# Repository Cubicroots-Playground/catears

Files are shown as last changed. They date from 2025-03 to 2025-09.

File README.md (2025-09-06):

# catears

This repository contains everything you need to build your own brightly lit cat ear hairband with widely adopted electronics.

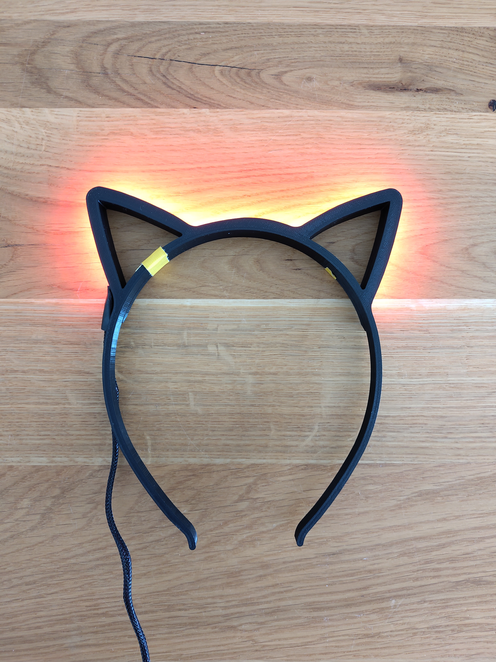
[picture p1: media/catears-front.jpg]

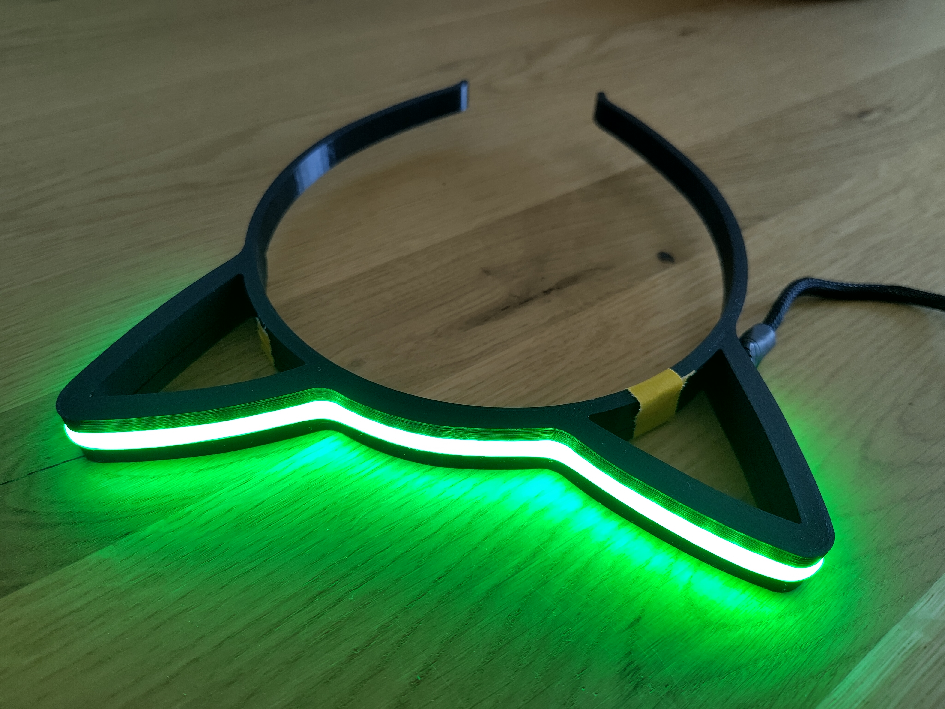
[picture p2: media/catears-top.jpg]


## Why?

This project got inspired by the satirical "Safety cat ears required" signs you might see in some hackspaces or at chaos events. Half joking I once said I will actually build "real" safety cat ears. This repository is the result of that.

## Build your own ones - Step by step!

### Item List

You will need the following items:

- Part 1 & 2 from the `models` folder printed with any 3D printer
- An enclosure for the microcontroller, I am using [this model](https://www.thingiverse.com/thing:4802020)
- 1x ESP8266 (I am using a "Wemos D1 Mini")
- 1x a few centimeters of a WS2811 LED strip 
- A bunch of cables to solder everything together (preferably flexible cable)
  - Either use a 3 core sealed cable or wrap 3 wires with a cable sleeve
- A button with 2 wires attached
- A Micro-USB to USB cable (can be pretty short)
- A USB power source (e.g. a power bank)
- Optional: A connector to solder between microcontroller and cat ears (e.g. JST SM 3 Pin)
- Some glue or tape to connect the 3D printed parts

Further, access to the following tools is needed:

- A soldering station/kit
- A computer with docker for the initial setup

#### Alternative Hardware

You totally can use other hardware components - some notes on swapping parts:

**Microcontroller**

Every microcontroller supported by ESPHome should work. At least 1 GPIO pin should be accessible. Using a different microcontroller requires adopting the ESPHome config.

**LED strip**

Looks best with a silicon diffusor on top - strips are available with a pre-applied one. Search for "COB" or "FCOB" LED strips with the WS2811 chip set.

You can use any other LED strip supported by ESPHome and the neopixel integration. However, using a different chip set requires to adopt the ESPHome config accordingly.

The 3D models are designed to accomodate a 12mm wide LED strip with a 2.65mm wide silicon diffusor on top.

#### Fitting the 3D printed Hairband

You can scale the hairband according to your needs. I seem to have a pretty big head, so the supplied model already is pretty large. It is roughly 20% larger than the "usual" cat ear hairbands in my hackspace. 

To scale the models import them into your favorite slicer and scale the x/y axis for the same amount (do not touch the z axis/height).

### Putting it together

See [the manual](./manual.md).

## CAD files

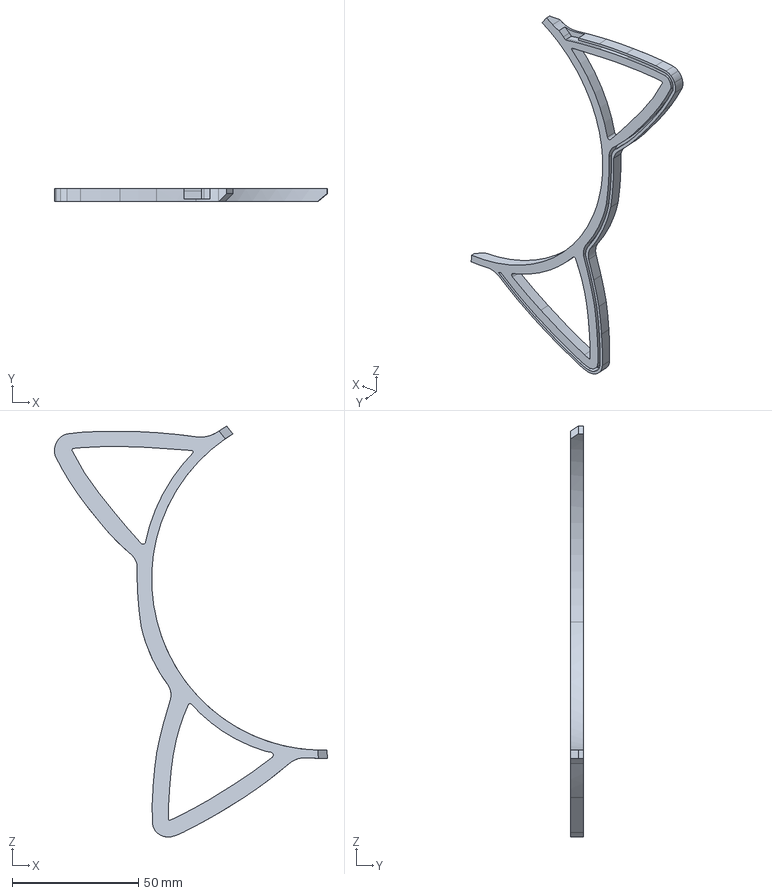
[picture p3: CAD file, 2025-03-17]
models/catears_part_2.FCStd
108.2 x 5.00 x 162.8 mm

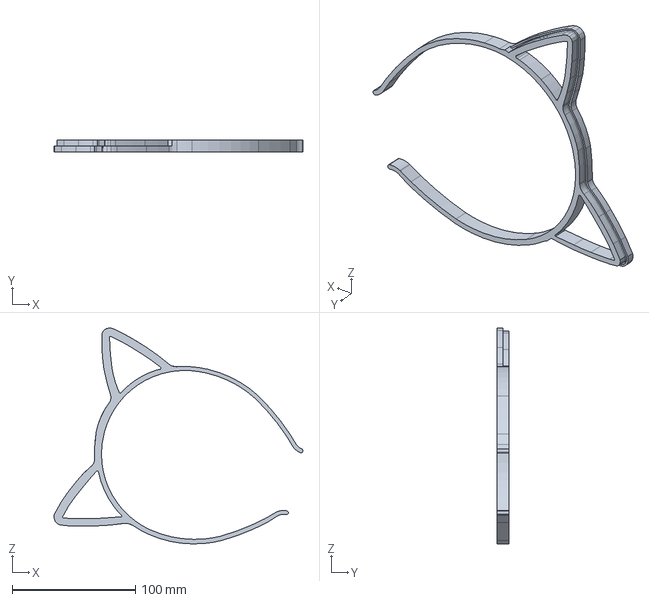
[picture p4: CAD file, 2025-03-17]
models/catears_part_1.FCStd
201.9 x 10.0 x 175.0 mm

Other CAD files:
models/catears_part_1.stl
models/catears_part_2.stl

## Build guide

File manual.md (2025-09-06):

# Manual: Putting it together

1. Print the hairband. Part 1 & 2 are needed.
   
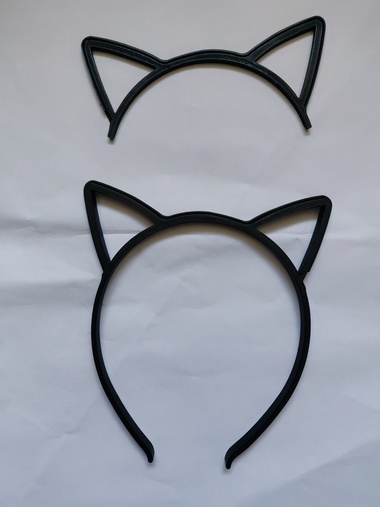
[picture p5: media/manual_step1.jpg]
   
2. Print an enclosure for the microcontroller. I am using [this model](https://www.thingiverse.com/thing:4802020)

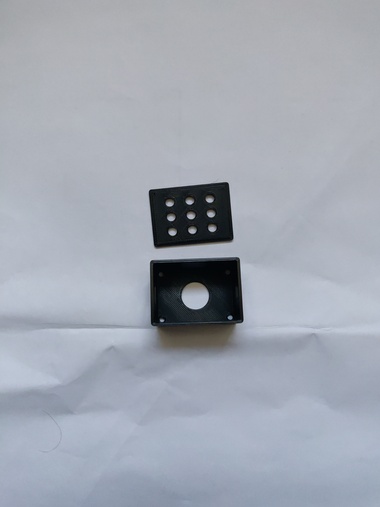
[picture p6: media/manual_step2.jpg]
   
3. Solder wires to your LED strip and connect them with the microcontroller.
   1. You can use a connector between them to easily plug and unplug them. I am using a "JST SM" connector.
   2. To make things look way more nice I suggest covering the cables with some cable sleeves.
   3. The LED strip runs on 5V.
   4. Connect the data wire of the LED strip to your microcontrollers `GPIO3` pin.
   
4. Install the Button
   1. Connect the Button to the 3V and GPIO16 pin.
   
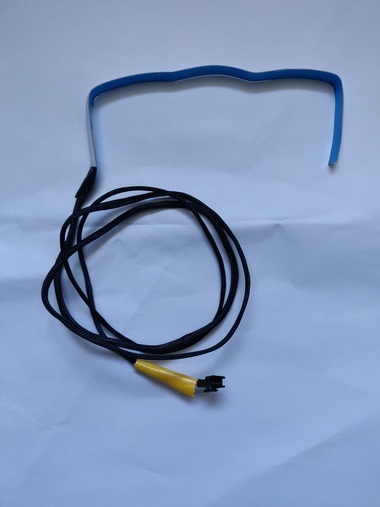
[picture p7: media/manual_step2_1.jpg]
   
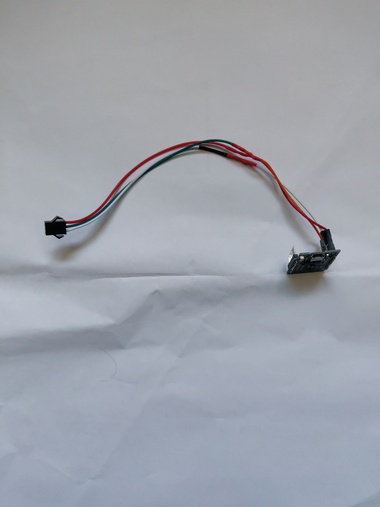
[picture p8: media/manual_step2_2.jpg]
   
5. Assemble the models.
   1. Put the LED strip into the thin groove along the top of the hairband of the bigger of the 2 models.
   2. Cut the LED strip to size.
   
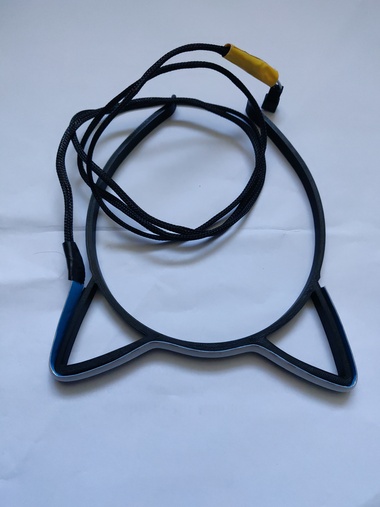
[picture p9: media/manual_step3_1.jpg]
   

   3. Put the second, smaller part on top and make sure the LED strip is fitting into its groove as well.
   4. Glue the parts together or use 2 thin strips of tape to hold them together.
   
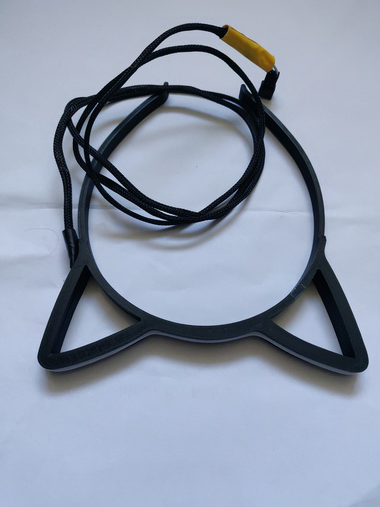
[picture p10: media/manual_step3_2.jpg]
   
6. Flash the microcontroller.
   1. Copy `esphome/secrets.example.yaml` to `esphome/secrets.yaml` and set your secrets.
   2. Connect the microcontroller to your computer via a USB cable.
   3. In a terminal run `(cd esphome && docker compose up)`
   4. Navigate your browser to `http://127.0.0.1:6052`.
   5. LogIn with user `admin` and password `admin`.
   6. Using the UI upload the `catears.yaml` to your microcontroller.
7. Put the microcontroller into the enclosure and connect everything.
   
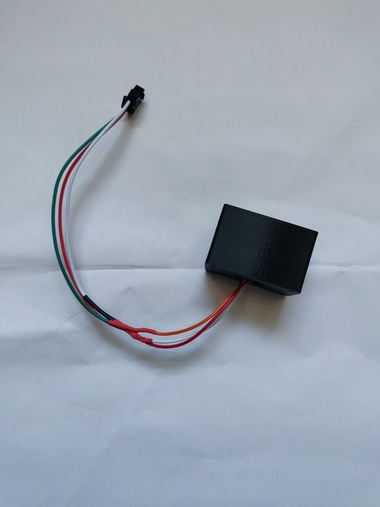
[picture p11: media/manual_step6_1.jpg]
   
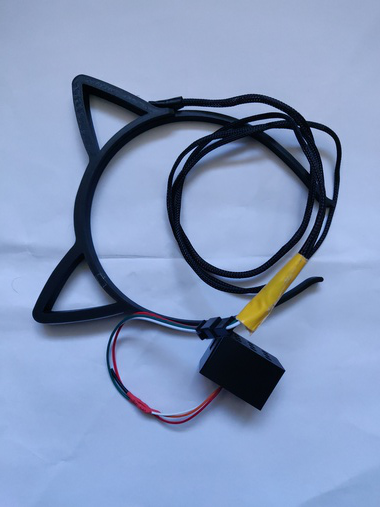
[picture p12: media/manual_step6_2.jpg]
   
8. Verify everything is working.
   1. Power the microcntroller (either by your computer or an external power source).
   2. Make sure the button works.
      1. Single short presses cycles through effects.
      2. Single long presses cycles through brightness.
      3. Single very long press (5-10s) enables WiFi.
   3. Navigate your browser to `http://catears.local/`, the ESPHome dashboard should be visible.
      - In case the given WiFi is not reachable the ESP will offer an access point called "catear" connect to it via the `ap_password` and navigate to `192.168.4.1` where the dashboard is located at 
   4. You can change the brightness, color and effects from this dashboard as well.

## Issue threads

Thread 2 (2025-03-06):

Feat: Housing for the microcontroller

CubicrootXYZ, 2025-03-06:
Add STLs for a housing that fits the microcontroller.

CubicrootXYZ, 2025-04-19:
Referencing to the enclosure in the readme

Closed 2025-04-19.

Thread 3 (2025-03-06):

Docu: Add more docu for using connectors & soldering

CubicrootXYZ, 2025-03-06:
Explain in more depth what connectors to use between LED strip and microcontroller. Add improved documentation about soldering things.

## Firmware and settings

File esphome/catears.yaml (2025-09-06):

globals:
   - id: active_effect
     type: int
     restore_value: yes
     initial_value: '0' 
   - id: brightness
     type: int
     restore_value: yes
     initial_value: '0' 

esphome:
  name: "catears"
  on_boot:
    - light.turn_on:
        id: leds
        brightness: 25%
        effect: Rainbow Pulse

# Define the used hardware.
esp8266:
  board: d1_mini

# Enable logging.
logger:

# Enable OTA updates.
ota:
  - platform: esphome
    password: ""

wifi:
  # Attempt to connect to this wifi.
  ssid: !secret wifi_ssid
  password: !secret wifi_password

  enable_on_boot: false

  # Enable fallback hotspot (captive portal) in case wifi connection fails.
  ap:
    ssid: "catears"
    password: !secret ap_password
    # Switch to access point mode early.
    ap_timeout: 5s
  
  on_connect:
    - light.turn_on:
        id: leds
        brightness: 25%
        effect: "Warning"
        red: 0%
        blue: 0%
        green: 100%

# Run webserver with dashboard to control cat ears.
web_server:
  # Allows accessing the webserver in ap mode at 192.168.4.1.
  local: true
  port: 80
  version: 3

# Setup the LEDs and effects.
light:
  - platform: neopixelbus
    id: leds
    type: GRB
    variant: WS2811
    pin: GPIO3
    num_leds: 25
    name: "NeoPixel Light"
    effects:
      - addressable_color_wipe:
          name: Random Color Wipe
      - addressable_rainbow:
          name: Rainbow Wipe
          speed: 40
          width: 10
      - addressable_scan:
          name: Scan Effect
          move_interval: 100ms
          scan_width: 3
      - addressable_fireworks:
          name: Fireworks Effect
          spark_probability: 30%
          use_random_color: true
      - addressable_lambda:
          name: Rainbow Pulse
          update_interval: 20ms
          lambda: |-
            static uint8_t h = 0;

            if (h > 365) {
              h = 0;
            }

            ESPHSVColor hsv_value(h, 255, 255);
            it.range(0, it.size()) = hsv_value.to_rgb();

            h = h+1;
      - addressable_lambda:
          name: Rainbow Wipe Improved
          update_interval: 25ms
          lambda: |-
            static uint16_t h = 0;

            if (h > 255) {
              h = 0;
            }

            uint16_t local_h = h;
            for (uint32_t i = 0; i < it.size(); i++) {
              ESPHSVColor hsv_value(local_h, 255, 255);
              it[i] = hsv_value.to_rgb();

              local_h = local_h + 2;
              if (local_h > 255) {
                local_h = 0;
              }
            }

            h = h+1;
      - addressable_lambda:
          name: Warning
          update_interval: 20ms
          lambda: |-
            const static uint16_t delta = 10;
            static uint32_t v = 0;

            if (v > 510) {
              v = 0;
            }

            uint32_t local_v = v;
            if (local_v > 255) {
              local_v = 510 - local_v;
            }

            local_v = (local_v*local_v) / 255;

            ESPHSVColor hsv_value(30, 255, local_v);
            it.range(0,delta) = hsv_value.to_rgb();
            it.range(delta,it.size()-delta) = Color(0,0,0);
            it.range(it.size()-delta,it.size()) = hsv_value.to_rgb();

            v = v+10;
      - addressable_lambda:
          name: Blitzer
          update_interval: 50ms
          lambda: |-
            const static uint16_t delta = 10;
            static uint16_t t = 0;

            if (t <= 5 || t == 8) {
              it.range(0,it.size()) = Color(0,0,0);
            } else {
              ESPHSVColor hsv_value(30, 255, 255);
              it.range(0,delta) = hsv_value.to_rgb();
              it.range(delta,it.size()-delta) = Color(0,0,0);
              it.range(it.size()-delta,it.size()) = hsv_value.to_rgb();
            }

            t = t+1;

            if (t > 10) {
              t = 0;
            }
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

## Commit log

2025-03-06 add initial files
    [catears_part_1.FCStd, catears_part_1.stl, catears_part_2.FCStd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]
2025-03-17 tweak led stripe grooves
    [catears_part_1.FCStd, catears_part_1.stl, catears_part_2.FCStd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]
2025-04-19 link to enclosure in parts list
2025-09-06 feat(esphome): diable wifi on default & add button as input
2025-09-06 docs: meniton new button
